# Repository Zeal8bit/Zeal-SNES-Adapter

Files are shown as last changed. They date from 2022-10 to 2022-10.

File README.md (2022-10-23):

## SNES controller adapter for Zeal 8-bit Computer

The goal of this project is to create an SNES controller adapter PCB for Zeal 8-bit Computer.

This repository includes:
* An example/driver written in Z80 assembly to communicate with the adapter
* A Kicad (v6) project for the PCB board
* Gerber files for PCB. If you don't want or can't open the Kicad project and generate gerber files, you can directly download the gerber files and send them to your favorite PCB manufacturer.

## License

Distributed under the Apache 2.0 License. See LICENSE file for more information.

You are free to use it for personal and commercial use, the boilerplate present in each file must not be removed.

## Contact

For any suggestion or request, you can contact me at contact [at] zeal8bit [dot] com or on the Discord server https://discord.gg/UzEjwRvBBb

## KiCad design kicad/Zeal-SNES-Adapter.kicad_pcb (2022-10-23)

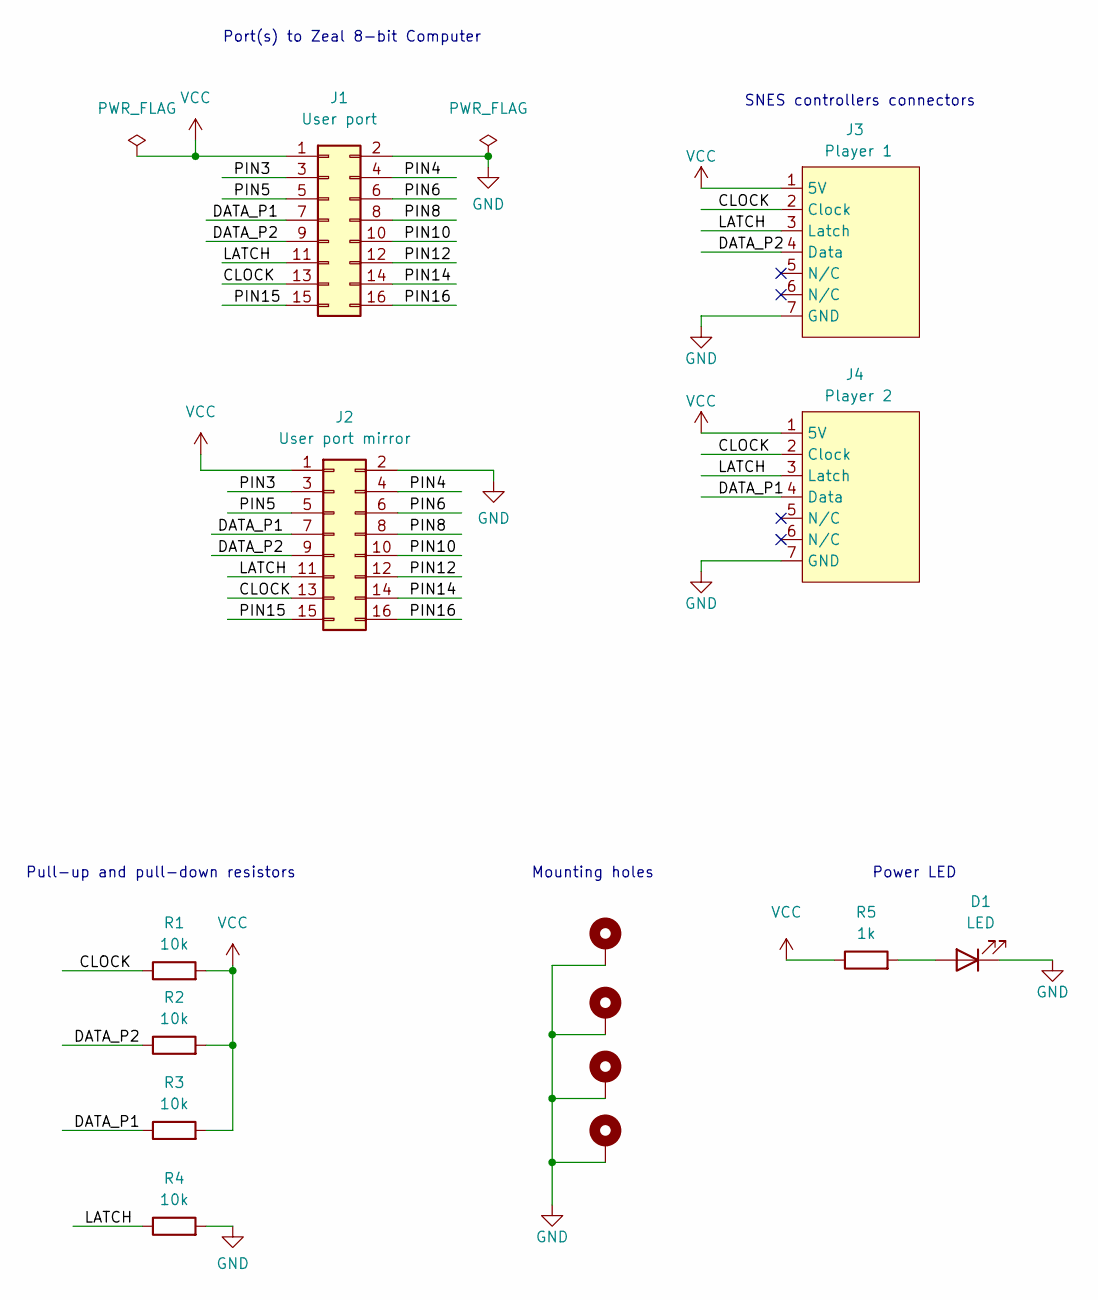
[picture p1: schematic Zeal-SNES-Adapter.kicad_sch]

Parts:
D1: LED; LED_D5.0mm
H1, H2, H3, H4: MountingHole_Pad; MountingHole_2.2mm_M2_Pad
J1: User port; PinHeader_2x08_P2.54mm_Horizontal
J2: User port mirror; PinHeader_2x08_P2.54mm_Vertical
J3: Player 1; SNES
J4: Player 2; SNES
R1, R2, R3, R4: 10k; R_Axial_DIN0207_L6.3mm_D2.5mm_P10.16mm_Horizontal
R5: 1k; R_Axial_DIN0207_L6.3mm_D2.5mm_P10.16mm_Horizontal

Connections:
/CLOCK: J1.13, J2.13, J3.2 (Clock), J4.2 (Clock), R1.1
/DATA_P1: J1.7, J2.7, J4.4 (Data), R3.1
/DATA_P2: J1.9, J2.9, J3.4 (Data), R2.1
/LATCH: J1.11, J2.11, J3.3 (Latch), J4.3 (Latch), R4.1
/PIN3: J1.3, J2.3
/PIN4: J1.4, J2.4
/PIN5: J1.5, J2.5
/PIN6: J1.6, J2.6
/PIN8: J1.8, J2.8
/PIN10: J1.10, J2.10
/PIN12: J1.12, J2.12
/PIN14: J1.14, J2.14
/PIN15: J1.15, J2.15
/PIN16: J1.16, J2.16
GND: D1.1 (K), H1.1, H2.1, H3.1, H4.1, J1.2, J2.2, J3.7 (GND), J4.7 (GND), R4.2
unnamed: D1.2 (A), R5.2
VCC: J1.1, J2.1, J3.1 (5V), J4.1 (5V), R1.2, R2.2, R3.2, R5.1

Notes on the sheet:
Mounting holes
Power LED
SNES controllers connectors
Pull-up and pull-down resistors
Port(s) to Zeal 8-bit Computer

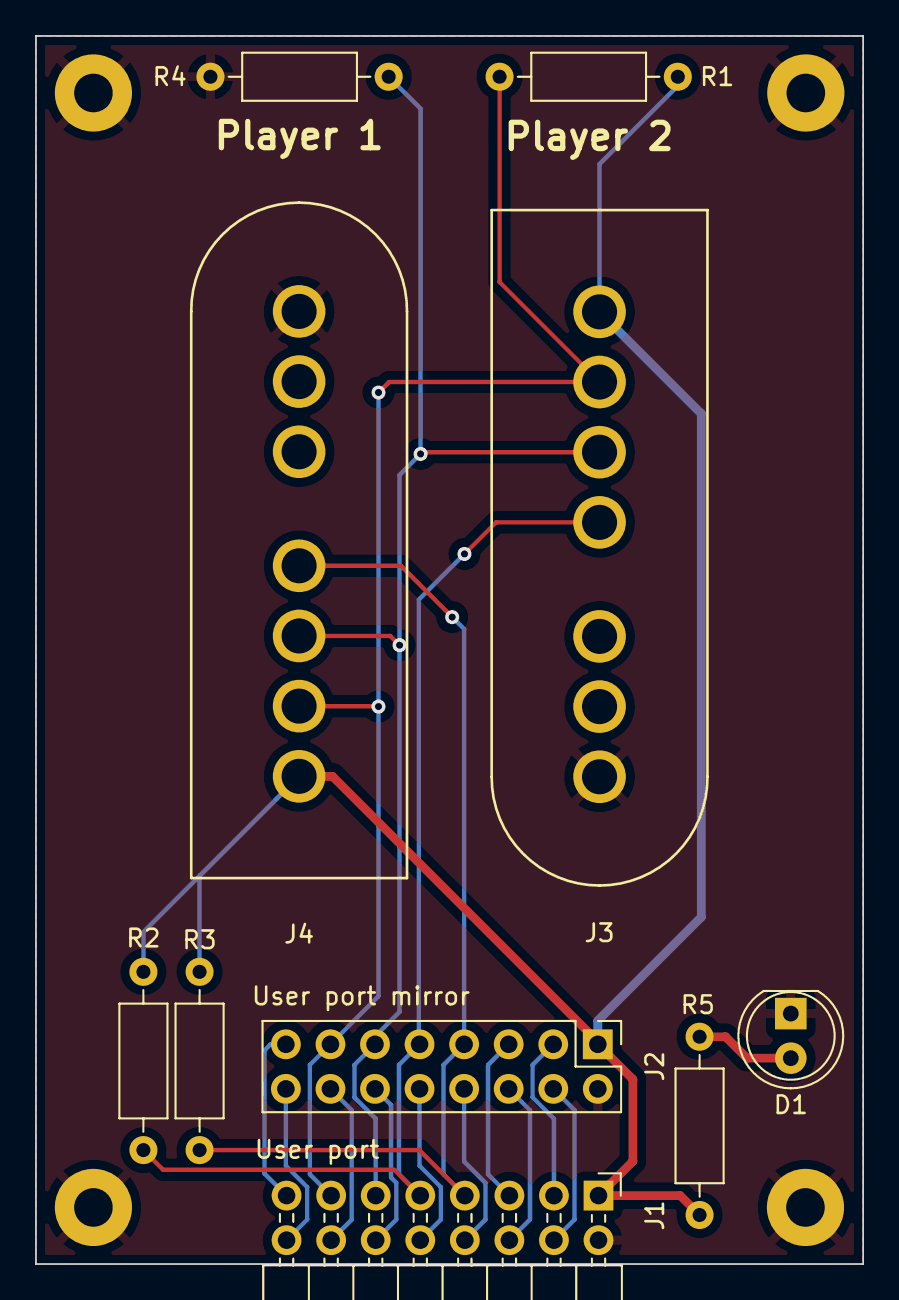
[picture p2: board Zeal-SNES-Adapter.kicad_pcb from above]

Board: 2 copper layers, 47.1 x 70.0 mm, 14 parts (0 on the bottom side), 17 nets.

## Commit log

2022-10-23 Add the SNES controller driver/example, written in Z80 assembly
2022-10-23 PCB: Add kicad project and gerber files
    [Zeal-SNES-Adapter-B_Cu.gbr, Zeal-SNES-Adapter-B_Mask.gbr, Zeal-SNES-Adapter-B_Paste.gbr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]
